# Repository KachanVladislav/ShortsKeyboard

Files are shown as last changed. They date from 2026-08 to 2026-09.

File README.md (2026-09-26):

# ShortsKeyboard v1.0

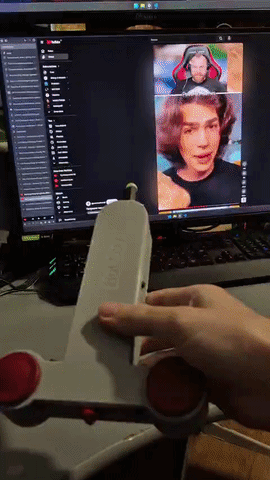
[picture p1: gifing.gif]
ogo


## Описание

Клавиатура для переключения видео - вперед/назад посредством встряски.

* ./3dmodel/ShortsKeyboardCase.FCStd - модель корпуса, в реальности USB подуключил сзади, спереди кнопка включения
* ./3dmodel/TumblerPowerOn.FCStd - кнопка включения (in process)
* ./shortKeyboard_sch/ - принципиальная схема + печатная плата основного модуля
* ./powerSwitch_sch/ - печатная плата кнопки включения - не влезла в корпус (tbd)

## Блок-схема
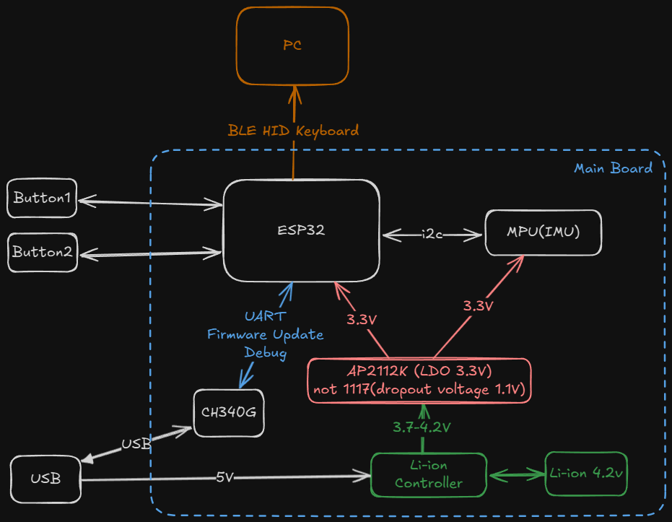
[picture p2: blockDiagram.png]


## График ускорения при встряске

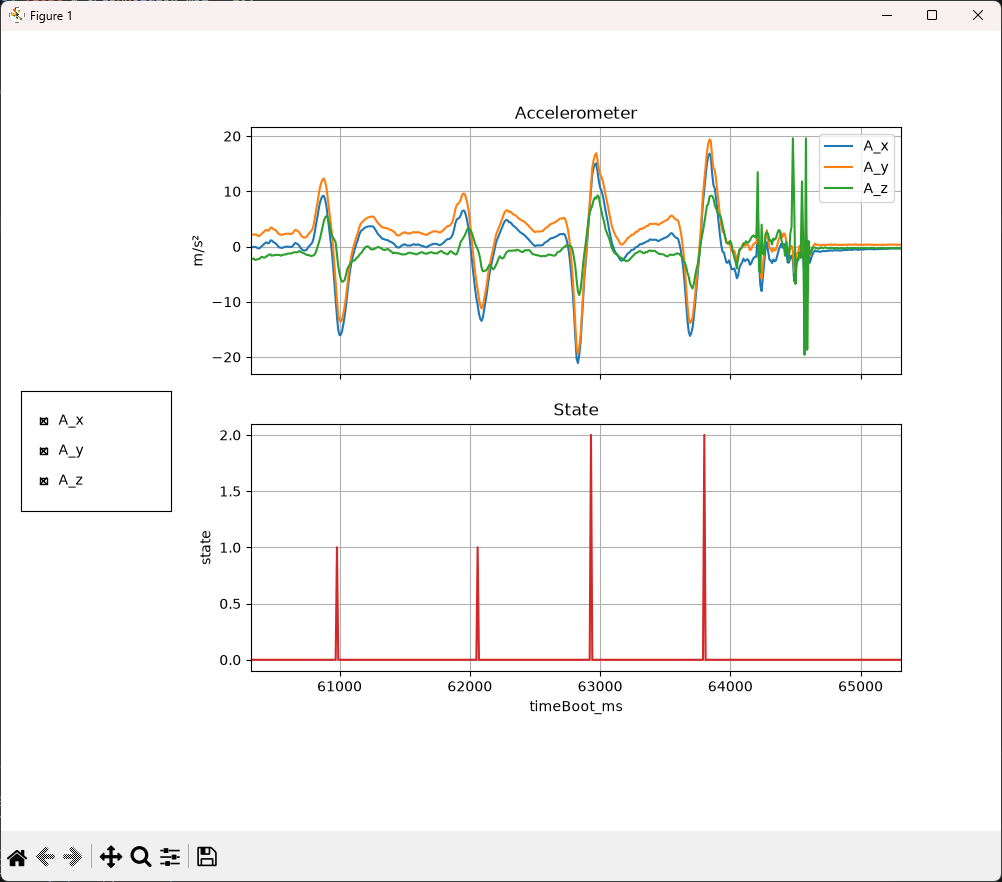
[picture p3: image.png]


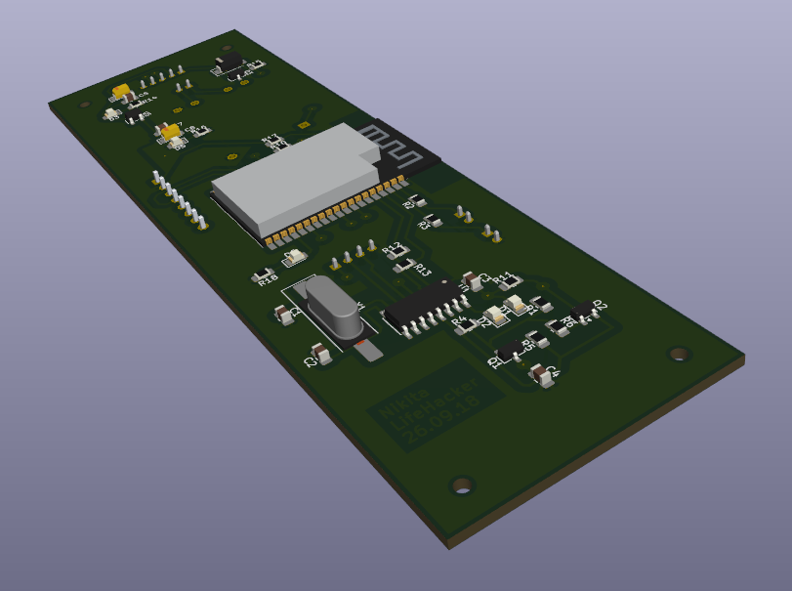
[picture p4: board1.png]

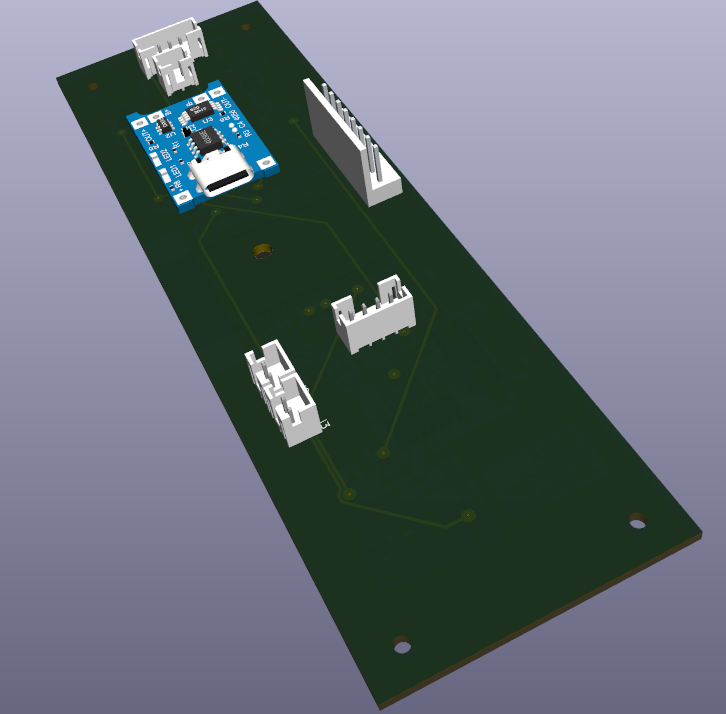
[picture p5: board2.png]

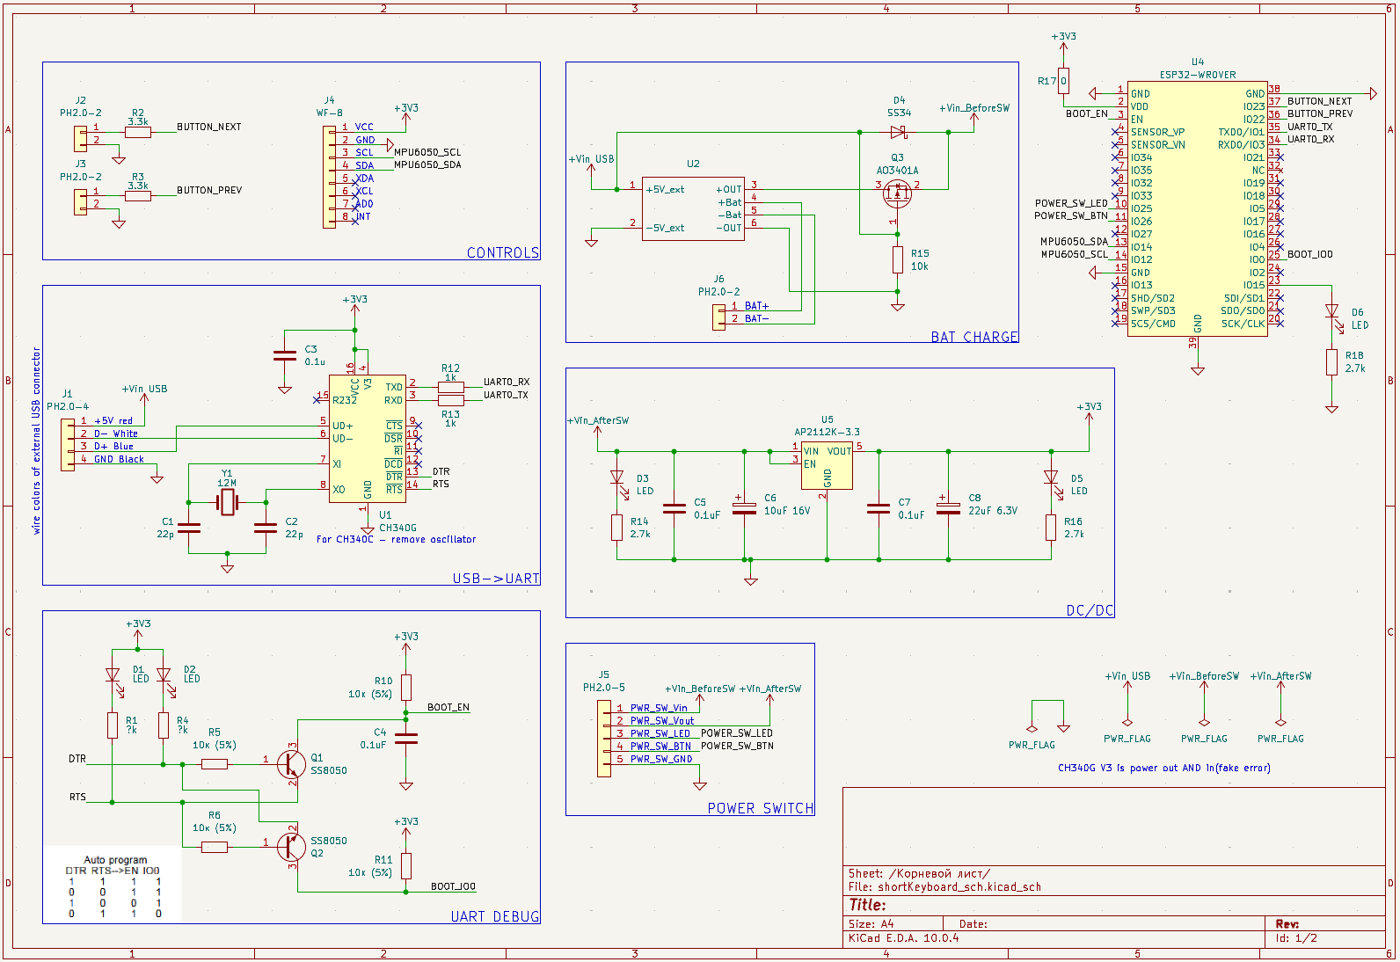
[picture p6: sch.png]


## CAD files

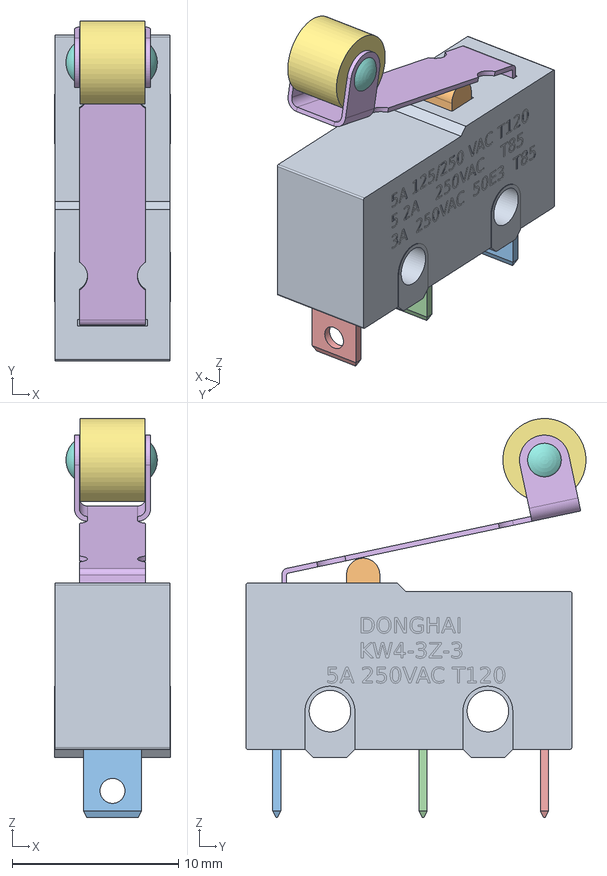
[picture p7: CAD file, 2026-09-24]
3dmodel/TumblerPowerOn.FCStd
7.00 x 20.5 x 24.0 mm
Case
Button
Contact
Contact001
Contact002
Lever
Roller
Axis

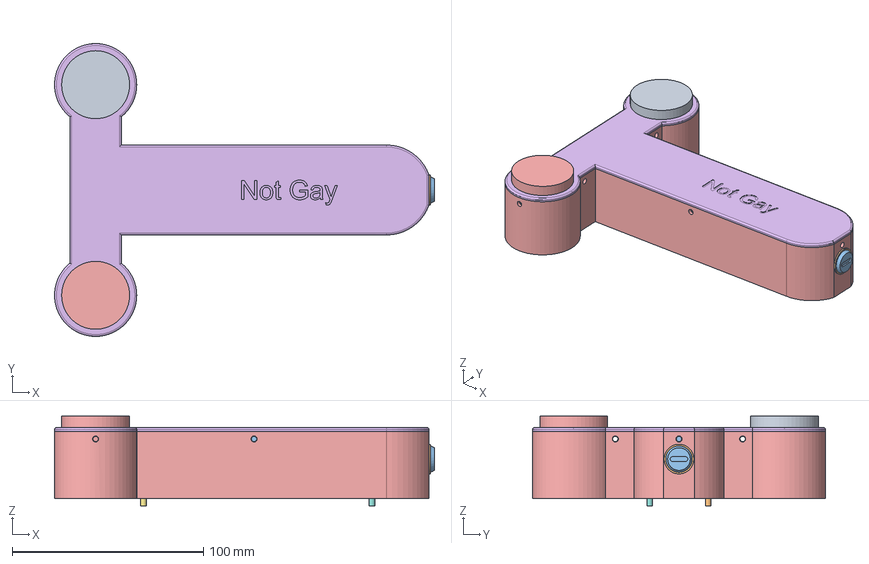
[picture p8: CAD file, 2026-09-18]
3dmodel/ShortsKeyboardCase.FCStd
198.5 x 153.0 x 47.0 mm
ButtonCumaz
Rubber
House
Skrew
ButtonCumaz001
pcb
standof_MF6
standof_MF6_2
standof_MF6_3
standof_MF6_4
SpaceForElectronics
BatteryCase
CaseBottom
CaseTop

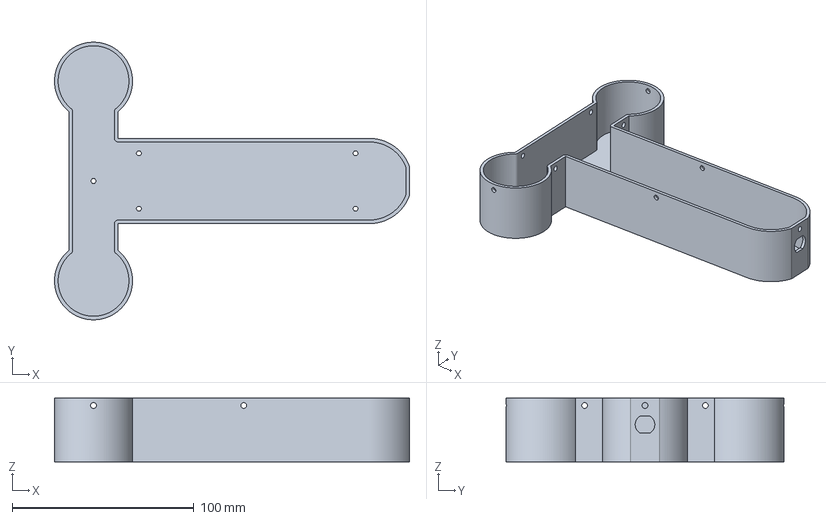
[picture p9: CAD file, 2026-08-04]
3dmodel/ShortsKeyboardCase-CaseBottom.3mf
195.6 x 153.0 x 35.0 mm

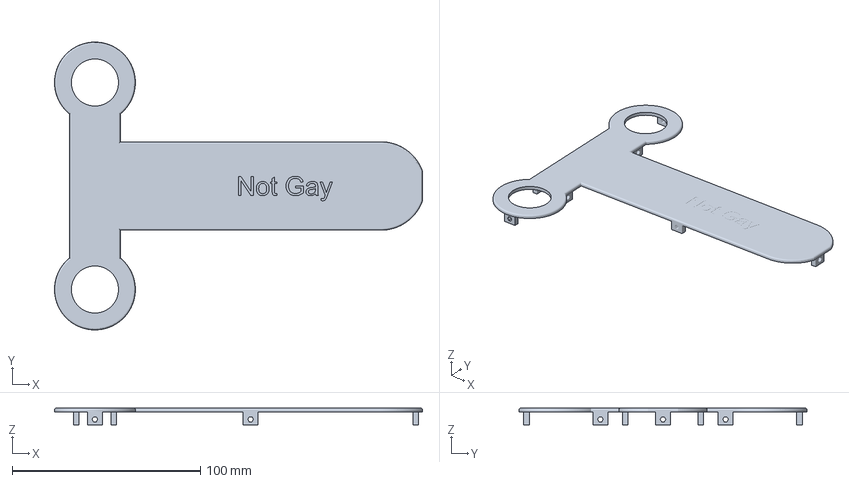
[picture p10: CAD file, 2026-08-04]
3dmodel/ShortsKeyboardCase-CaseTop.3mf
195.6 x 153.0 x 9.00 mm

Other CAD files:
3dmodel/end_switch.FCStd
3dmodel/KW4-3Z-3.step

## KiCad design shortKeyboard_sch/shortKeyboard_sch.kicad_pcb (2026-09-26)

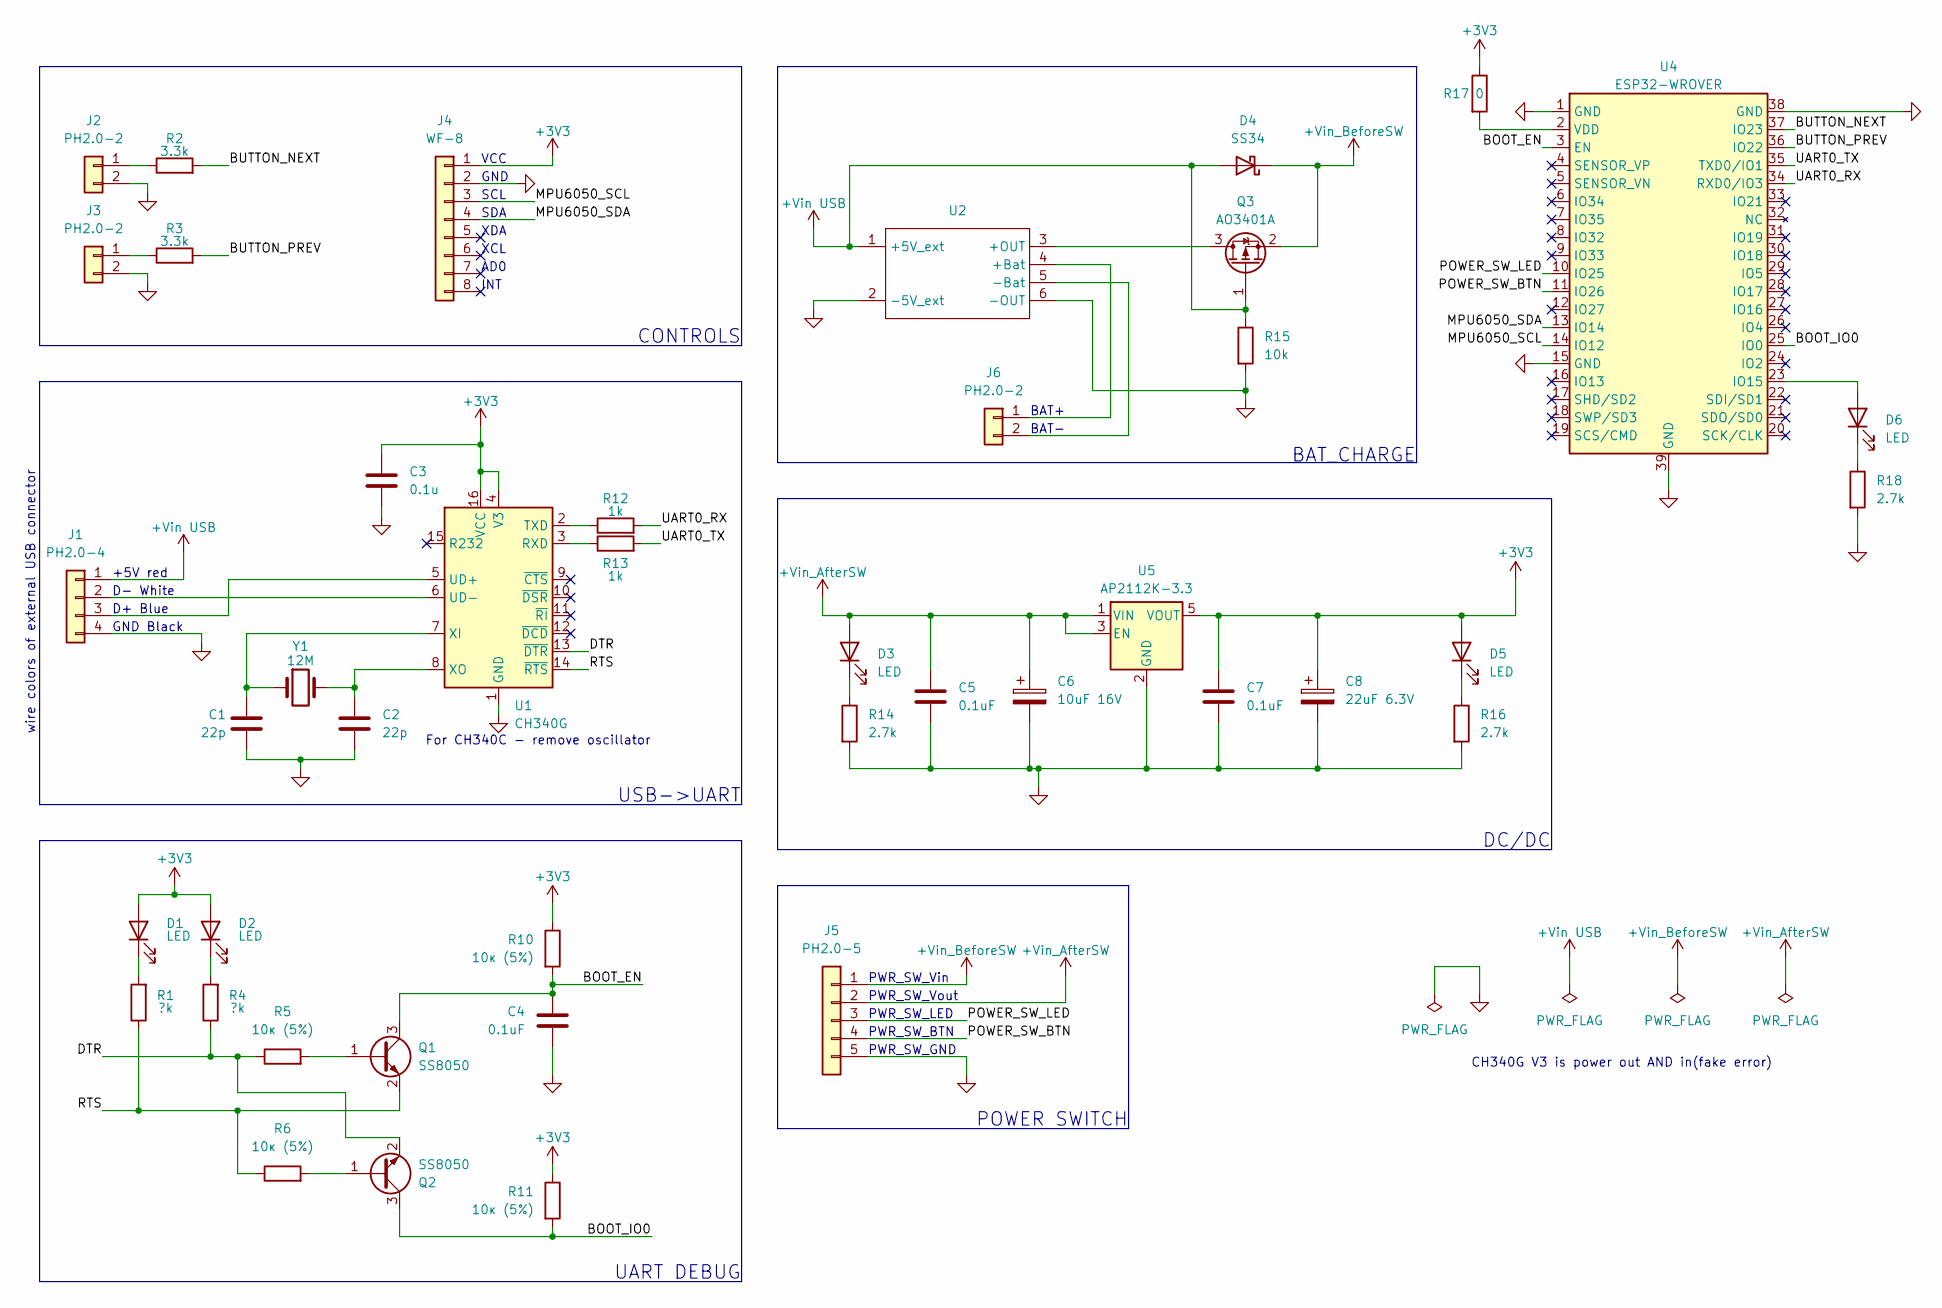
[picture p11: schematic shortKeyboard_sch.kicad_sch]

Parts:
C1, C2: 22p; C_0805_2012Metric_Pad1.18x1.45mm_HandSolder
C3: 0.1u; C_0805_2012Metric_Pad1.18x1.45mm_HandSolder
C4, C5, C7: 0.1uF; C_0805_2012Metric_Pad1.18x1.45mm_HandSolder
C6: 10uF 16V; CP_EIA-3216-18_Kemet-A_HandSolder
C8: 22uF 6.3V; CP_EIA-3216-18_Kemet-A_HandSolder
D1, D2, D3, D5, D6: LED; LED_0805_2012Metric_Pad1.15x1.40mm_HandSolder
D4: SS34; D_SMA
J1: PH2.0-4
J2, J3, J6: PH2.0-2
J4: WF-8
J5: PH2.0-5
Q1, Q2: SS8050; SOT-23
Q3: AO3401A; SOT-23
R1, R4: ?k; R_0805_2012Metric_Pad1.20x1.40mm_HandSolder
R2, R3: 3.3k; R_0805_2012Metric_Pad1.20x1.40mm_HandSolder
R5, R6, R10, R11: 10к (5%); R_0805_2012Metric_Pad1.20x1.40mm_HandSolder
R12, R13: 1k; R_0805_2012Metric_Pad1.20x1.40mm_HandSolder
R14, R16, R18: 2.7k; R_0805_2012Metric_Pad1.20x1.40mm_HandSolder
R15: 10k; R_0805_2012Metric_Pad1.20x1.40mm_HandSolder
R17: 0; R_0805_2012Metric_Pad1.20x1.40mm_HandSolder
U1: CH340G; SOIC-16_3.9x9.9mm_P1.27mm
U2: TP4056_Module_CD_MicroUsb
U4: ESP32-WROVER; ESP32-WROVER-handSoldering
U5: AP2112K-3.3; SOT-23-5
Y1: 12M; Crystal_SMD_HC49-SD_HandSoldering

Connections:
+3V3: C3.1, C7.1, C8.1, D1.2 (A), D2.2 (A), D5.2 (A), J4.1, R10.1, R11.1, R17.1, U1.4 (V3), U1.16 (VCC), U5.5 (VOUT)
+Vin USB: D4.2 (A), J1.1, Q3.1 (G), R15.1, U2.1 (+5V_ext)
+Vin_AfterSW: C5.1, C6.1, D3.2 (A), J5.2 (Pin_1), U5.1 (VIN), U5.3 (EN)
+Vin_BeforeSW: D4.1 (K), J5.1, Q3.2 (S)
/Корневой лист/BOOT_EN: C4.1, Q1.3 (C), R10.2, U4.3 (EN)
/Корневой лист/BOOT_IO0: Q2.3 (C), R11.2, U4.25 (IO0)
/Корневой лист/BUTTON_NEXT: R2.2, U4.37 (IO23)
/Корневой лист/BUTTON_PREV: R3.2, U4.36 (IO22)
/Корневой лист/DTR: Q2.2 (E), R4.1, R5.1, U1.13 (~DTR)
/Корневой лист/MPU6050_SCL: J4.3, U4.14 (IO12)
/Корневой лист/MPU6050_SDA: J4.4, U4.13 (IO14)
/Корневой лист/POWER_SW_BTN: J5.4 (Pin_1), U4.11 (IO26)
/Корневой лист/POWER_SW_LED: J5.3 (Pin_2), U4.10 (IO25)
/Корневой лист/RTS: Q1.2 (E), R1.1, R6.1, U1.14 (~RTS)
/Корневой лист/UART0_RX: R12.2, U4.34 (RXD0/IO3)
/Корневой лист/UART0_TX: R13.2, U4.35 (TXD0/IO1)
GND: C1.2, C2.2, C3.2, C4.2, C5.2, C6.2, C7.2, C8.2, J1.4 (Pin_1), J2.2, J3.2, J4.2, J5.5 (Pin_1), R14.2, R15.2, R16.2, R18.2, U1.1 (GND), U2.2 (-5V_ext), U2.6 (-OUT), U4.1 (GND), U4.15 (GND), U4.38 (GND), U4.39 (GND), U5.2 (GND)
unnamed: D1.1 (K), R1.2
unnamed: D2.1 (K), R4.2
unnamed: D3.1 (K), R14.1
unnamed: D5.1 (K), R16.1
unnamed: D6.2 (A), U4.23 (IO15)
unnamed: D6.1 (K), R18.1
unnamed: J1.3 (Pin_2), U1.5 (UD+)
unnamed: J2.1, R2.1
unnamed: J3.1, R3.1
unnamed: J6.1, U2.4 (+Bat)
unnamed: J6.2, U2.5 (-Bat)
unnamed: Q1.1 (B), R5.2
unnamed: Q2.1 (B), R6.2
unnamed: Q3.3 (D), U2.3 (+OUT)
unnamed: R13.1, U1.3 (RXD)
unnamed: R12.1, U1.2 (TXD)
unnamed: J1.2 (Pin_1), U1.6 (UD-)
unnamed: C1.1, U1.7 (XI), Y1.1
unnamed: C2.1, U1.8 (XO), Y1.2
unnamed: R17.2, U4.2 (VDD)

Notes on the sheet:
BAT_CHARGE
INT
PWR_SW_LED
PWR_SW_GND
SDA
POWER SWITCH
GND Black
CONTROLS
XDA
UART DEBUG
SCL
For CH340C - remove oscillator
PWR_SW_Vout
DC/DC
BAT-
GND
VCC
D- White
PWR_SW_BTN
XCL
CH340G V3 is power out AND in(fake error)
PWR_SW_Vin
D+ Blue
AD0
+5V red
USB->UART
BAT+
wire colors of external USB connector

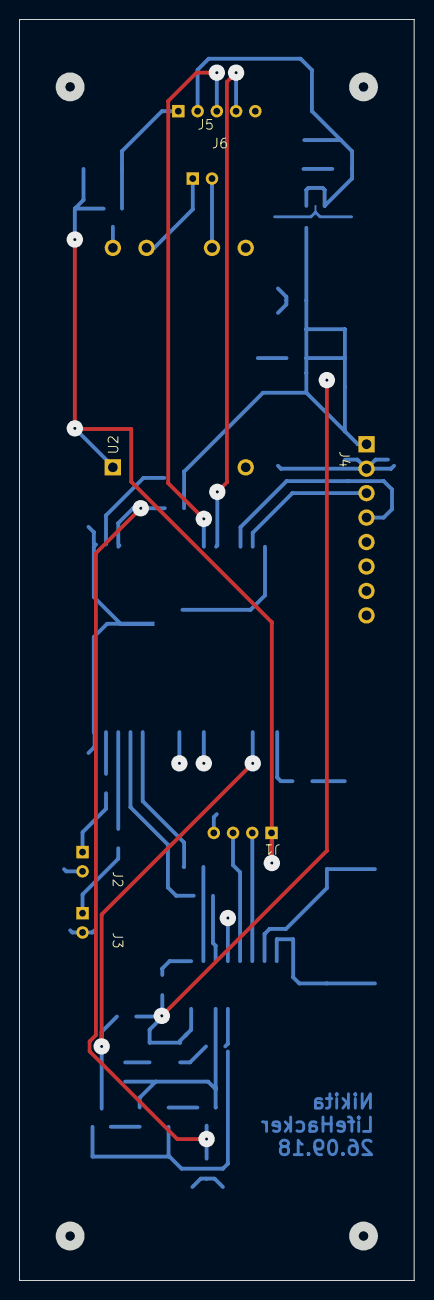
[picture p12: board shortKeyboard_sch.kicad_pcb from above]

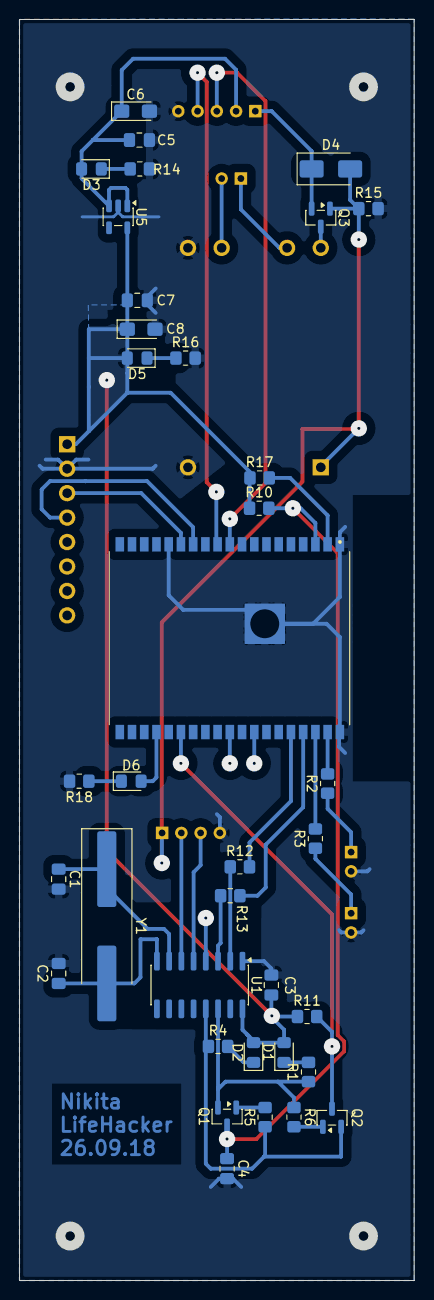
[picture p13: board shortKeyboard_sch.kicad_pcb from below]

Board: 2 copper layers, 41.0 x 131.0 mm, 43 parts (36 on the bottom side), 37 nets.

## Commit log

2026-08-05 SCH change buttons connector to B1_GND_B2_GND - so buttons conectors independent
    [shortKeyboard_sch.kicad_sch]
2026-08-07 update schematic, add mpu pins
    [shortKeyboard_sch.kicad_sch]
2026-09-18 intermediate new pcb version again
    [ShortsKeyboardCase.FCStd, esp_wroom_pins.kicad_sch, shortKeyboard_sch.kicad_pcb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]
2026-09-24 v1.0 commit
    [KW4-3Z-3.step, TumblerPowerOn.FCStd, end_switch.FCStd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]
2026-09-26 update pcb(1117->ap2112) + readme images
    [shortKeyboard_sch.kicad_pcb, shortKeyboard_sch.kicad_sch]
